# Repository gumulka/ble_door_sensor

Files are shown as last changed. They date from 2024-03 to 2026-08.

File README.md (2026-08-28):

# Bluetooth Window/Door Sensor

A simple project to observe a window or door is open/closed.
It works like most other sensors as well. A magnet has to get attached to the door and
if it comes near the board, it is detected and the state of the window or door is updated.

## How to build

If you are new to Zephyr, read the [Getting Started Guide](https://docs.zephyrproject.org/latest/develop/getting_started/index.html).
Afterwards you can clone and build this project with:

```bash
west init -m https://github.com/gumulka/ble_door_sensor --mr main door_sensor
cd door_sensor
west update
cd ble_door_sensor
```

### Bootloader

The bootloader will load and verify the image that is executed. To make it
easier to upgrade the device, two images are saved on the device and only one is
being executed, while the other is a standby for updating. The bootloader cannot
be upgraded via ble, but the image can be. Therefore making it possible to
upgrade devices in the field.

If you have a unprogrammed device, use this to build and flash the bootloader:

```bash
west build -p -b ble_door_sensor -d build_mcuboot ../bootloader/mcuboot/boot/zephyr/ -- -DCONFIG_BOOT_SIGNATURE_TYPE_ECDSA_P256=y
west flash -d build_mcuboot
```

### Application

The application is different from the bootloader and is what is in need of
updates/upgrades.

```bash
west build -p -b ble_door_sensor app
west flash
```

It is also possible to build the application with debug output for the UART
on the backside of the board.
This is disabled by default as it has a significant influence on battery.

```bash
west build -p -b ble_door_sensor app -- -DEXTRA_CONF_FILE=="debug.conf"
```

### Energy sensor

When I wanted to integrate energy consumption into home assistant without
having to order new hardware, I soldered two resistors to the board and
converted it into an energy monitor.
A 1M Ohm between VCC and AIN0 and 22k Ohm between AIN0 and GND.
This can be configured with:

```bash
west build -p -b ble_door_sensor app -- -DEXTRA_DTC_OVERLAY_FILE=="energy-tracker.dtsi"
```

## Update via BLE

If you have an already running device and just want to upgrade to the latest
firmware.

Either with the nRF Connect App, which can be quite handy, or in the commandline
use these steps:

```bash
sudo mcumgr --conntype ble --connstring ctlr_name=hci0,peer_name='Sensor' image upload build/zephyr/zephyr.signed.bin
sudo mcumgr --conntype ble --connstring ctlr_name=hci0,peer_name='Sensor' image list
```

Use the second hash provided from the second command to alter the following:

```bash
sudo mcumgr --conntype ble --connstring ctlr_name=hci0,peer_name='Sensor' image test "HASH_FROM_OUTPUT"
sudo mcumgr --conntype ble --connstring ctlr_name=hci0,peer_name='Sensor' reset
# wait for the system to restart and if you are sure, that the update was successful then
sudo mcumgr  --conntype ble --connstring ctlr_name=hci0,peer_name='Sensor' image confirm "HASH_FROM_OUTPUT"
```

More information about the general procedure can be found [here](https://docs.zephyrproject.org/latest/samples/subsys/mgmt/mcumgr/smp_svr/README.html)
and [here](https://docs.zephyrproject.org/latest/services/device_mgmt/mcumgr.html)

> [!TIP]
> I have seen a few errors when trying to upload the image and found that it
> works best, if I cancel the upload command after a few seconds and restart it
> a few seconds later, basically splitting the upload into 4-5 chunks instead
> of uploading it as a whole.

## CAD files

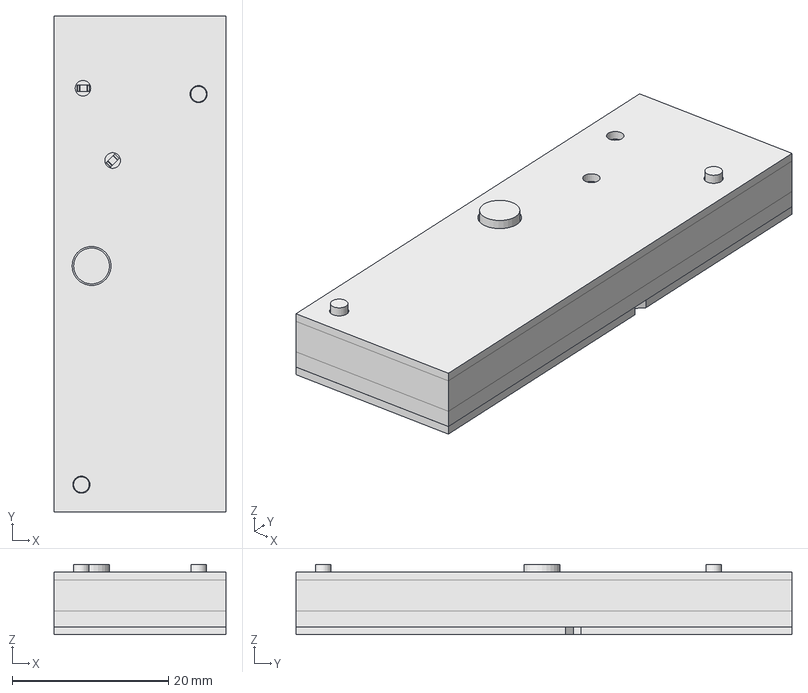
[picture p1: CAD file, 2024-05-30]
Case/Case.FCStd
22.0 x 63.5 x 9.00 mm
Crystal_SMD_3225-4Pin_3.2x2.5mm
C_0402_1005Metric
UQFN-48-1EP_6x6mm_Pitch0.4mm
C_0402_1005Metric002
C_0402_1005Metric004
C_0603_1608Metric
LinkGroup
LinkGroup001
LinkGroup002
L_0603_1608Metric
BatteryHolder_Keystone_3034_1x20mm
R_0402_1005Metric
C_0402_1005Metric006
R_0402_1005Metric002
LED_0603_1608Metric
R_0402_1005Metric004
SHTC1
SHTC002
SHTC003
SHTC004
SHTC005
SHTC006
SHTC007
SHTC008
SHTC009
SHTC010
R_0402_1005Metric006
R_0402_1005Metric008
C_0402_1005Metric008
C_0402_1005Metric010
C_0402_1005Metric012
SOT_23_6
C_0402_1005Metric014
SW_SPST_TL3342
C_0402_1005Metric016
LED_0603_1608Metric002
R_0402_1005Metric010
R_0402_1005Metric012
C_0402_1005Metric018
L_0402_1005Metric
L_0402_1005Metric002
C_0603_1608Metric002
C_0402_1005Metric020
Bottom
Top
Button

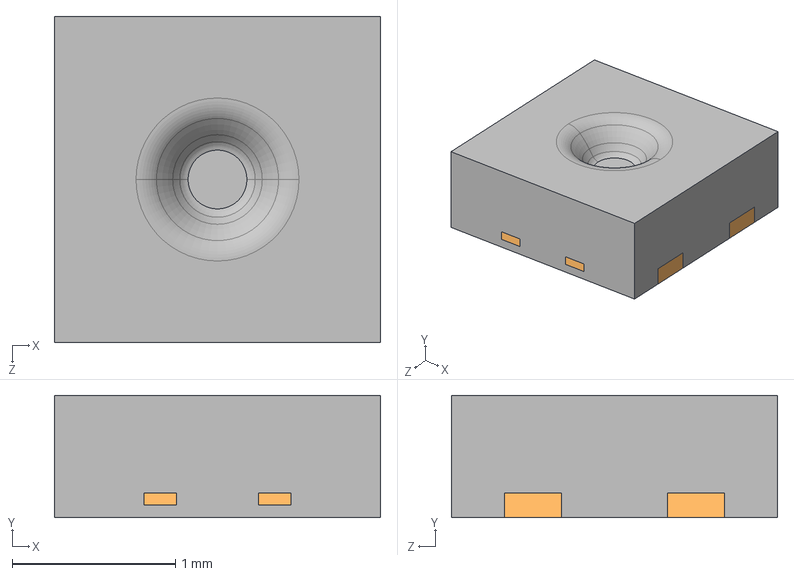
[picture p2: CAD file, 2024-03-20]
kicad/3D-Models/Sensirion-SHTC3.step
2.00 x 0.75 x 2.00 mm

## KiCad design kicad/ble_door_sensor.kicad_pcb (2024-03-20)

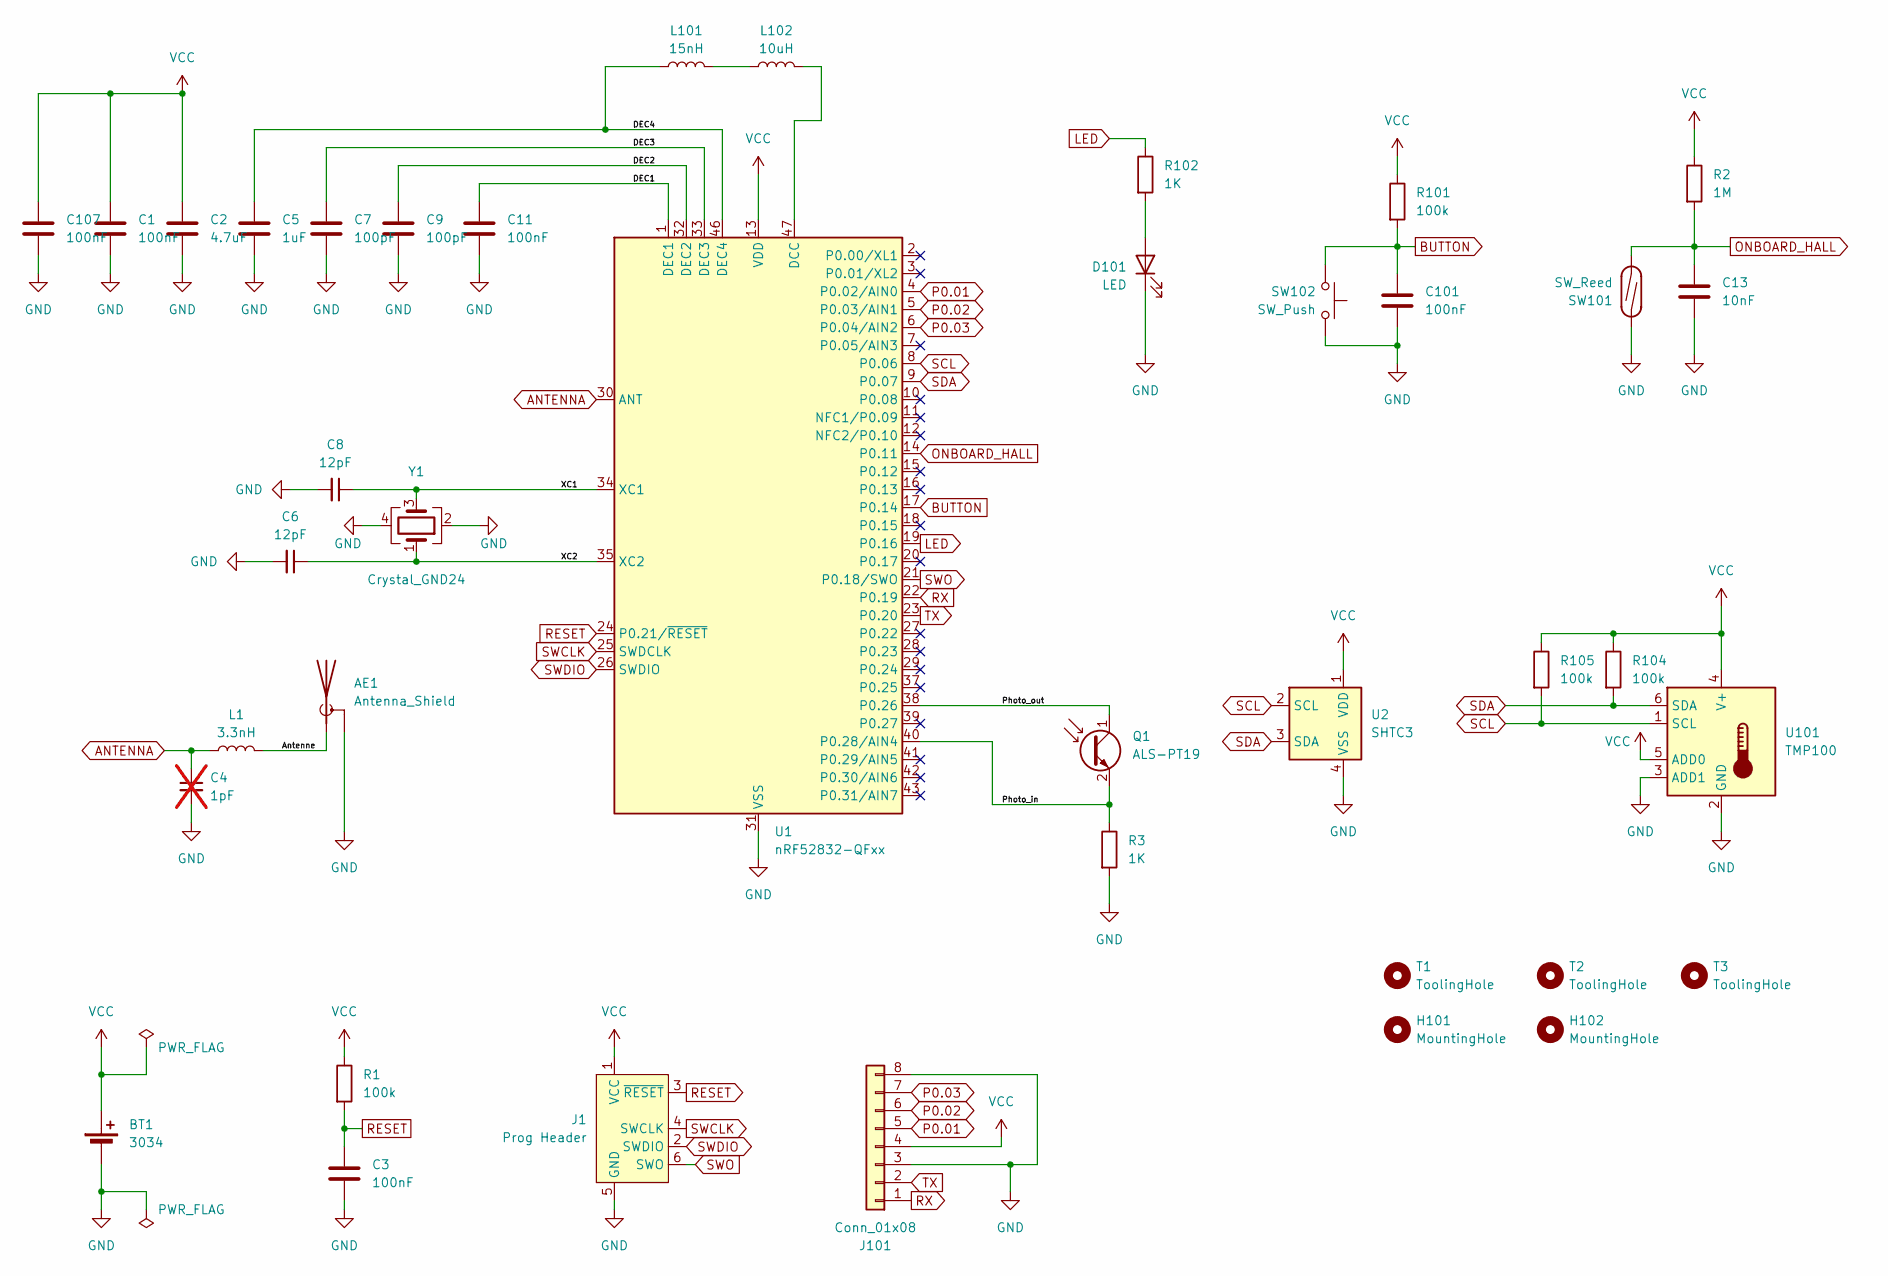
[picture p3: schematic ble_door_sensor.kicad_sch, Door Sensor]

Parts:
AE1: Antenna_Shield; Texas_SWRA117D_2.4GHz_Right
BT1: 3034; BatteryHolder_Keystone_3034_1x20mm; MPN 3034TR; LCSC# C5213768
C1, C3, C11, C101, C107: 100nF; C_0402_1005Metric; MPN 100nF 0402; LCSC# C1525
C2: 4.7uF; C_0603_1608Metric; MPN 4,7uF 0603; LCSC# C19666
C4: 1pF; C_0402_1005Metric; not fitted
C5: 1uF; C_0603_1608Metric; MPN 1uF 0603; LCSC# C15849
C6, C8: 12pF; C_0402_1005Metric; MPN 12pF 0402; LCSC# C1547
C7, C9: 100pF; C_0402_1005Metric; MPN 100pF 0402; LCSC# C1546
C13: 10nF; C_0402_1005Metric; MPN 10nF 0402; LCSC# C15195
D101: LED; LED_0603_1608Metric; MPN KP-1608SGC; LCSC# C72043
H101, H102: MountingHole; MountingHole_2.2mm_M2
J1: Prog Header; Tag-Connect_TC2030-IDC-NL_2x03_P1.27mm_Vertical
J101: Conn_01x08; PinHeader_1x08_P2.54mm_Vertical_SMD_Pin1Left
L1: 3.3nH; L_0402_1005Metric; MPN LQG15HS3N3C02D; LCSC# C14033
L101: 15nH; L_0402_1005Metric; MPN LQW15AN15NH00D; LCSC# C27143
L102: 10uH; L_0603_1608Metric; MPN MLZ1608E100MT; LCSC# C1035
Q1: ALS-PT19; LED_0603_1608Metric; MPN ALS-PT19-315C/L177/TR8; LCSC# C146233
R1, R101, R104, R105: 100k; R_0402_1005Metric; MPN 100K; LCSC# C25741
R2: 1M; R_0402_1005Metric; MPN 1M; LCSC# C26083
R3, R102: 1K; R_0402_1005Metric; MPN 1K; LCSC# C11702
SW101: SW_Reed; reed_contact
SW102: SW_Push; SW_SPST_TL3342; MPN TS-1187A-B-A-B; LCSC# C318884
T1, T2, T3: ToolingHole; JLCPCB_Mounting_hole
U1: nRF52832-QFxx; QFN-48-1EP_6x6mm_P0.4mm_EP4.6x4.6mm; MPN NRF52832-QFAA-R; LCSC# C77540
U2: SHTC3; Sensirion_DFN-4-1EP_2x2mm_P1mm_EP0.7x1.6mm; MPN SHTC3-TR-10KS; LCSC# C2880044
U101: TMP100; SOT-23-6; MPN TMP100NA/3K; LCSC# C31810
Y1: Crystal_GND24; Crystal_SMD_3225-4Pin_3.2x2.5mm; MPN X322532MOB4SI; LCSC# C9009

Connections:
/Antenne: AE1.1 (A), L1.2
/DEC1: C11.1, U1.1 (DEC1)
/DEC2: C9.1, U1.32 (DEC2)
/DEC3: C7.1, U1.33 (DEC3)
/DEC4: C5.1, L101.1, U1.46 (DEC4)
/Photo_in: Q1.2 (E), R3.1, U1.40 (P0.28/AIN4)
/Photo_out: Q1.1 (C), U1.38 (P0.26)
/XC1: C8.1, U1.34 (XC1), Y1.3
/XC2: C6.1, U1.35 (XC2), Y1.1
ANTENNA: C4.1, L1.1, U1.30 (ANT)
BUTTON: C101.1, R101.2, SW102.2, U1.17 (P0.14)
GND: AE1.2 (Shield), BT1.2 (-), C1.2, C2.2, C3.2, C4.2, C5.2, C6.2, C7.2, C8.2, C9.2, C11.2, C13.2, C101.2, C107.2, D101.1 (K), J1.5 (GND), J101.3, J101.8, R3.2, SW101.2, SW102.1, U1.31 (VSS), U1.45 (VSS), U1.49 (VSS), U2.4 (VSS), U101.2 (GND), U101.3 (ADD1), Y1.2, Y1.4
LED: R102.1, U1.19 (P0.16)
unnamed: D101.2 (A), R102.2
unnamed: L101.2, L102.1
unnamed: L102.2, U1.47 (DCC)
ONBOARD_HALL: C13.1, R2.2, SW101.1, U1.14 (P0.11)
P0.01: J101.5, U1.4 (P0.02/AIN0)
P0.02: J101.6, U1.5 (P0.03/AIN1)
P0.03: J101.7, U1.6 (P0.04/AIN2)
RESET: C3.1, J1.3 (~RESET), R1.2, U1.24 (P0.21/~RESET)
RX: J101.1, U1.22 (P0.19)
SCL: R105.2, U1.8 (P0.06), U2.2 (SCL), U101.1 (SCL)
SDA: R104.2, U1.9 (P0.07), U2.3 (SDA), U101.6 (SDA)
SWCLK: J1.4 (SWCLK), U1.25 (SWDCLK)
SWDIO: J1.2 (SWDIO), U1.26 (SWDIO)
SWO: J1.6 (SWO), U1.21 (P0.18/SWO)
TX: J101.2, U1.23 (P0.20)
VCC: BT1.1 (+), C1.1, C2.1, C107.1, J1.1 (VCC), J101.4, R1.1, R2.1, R101.1, R104.1, R105.1, U1.13 (VDD), U1.36 (VDD), U1.48 (VDD), U2.1 (VDD), U101.4 (V+), U101.5 (ADD0)

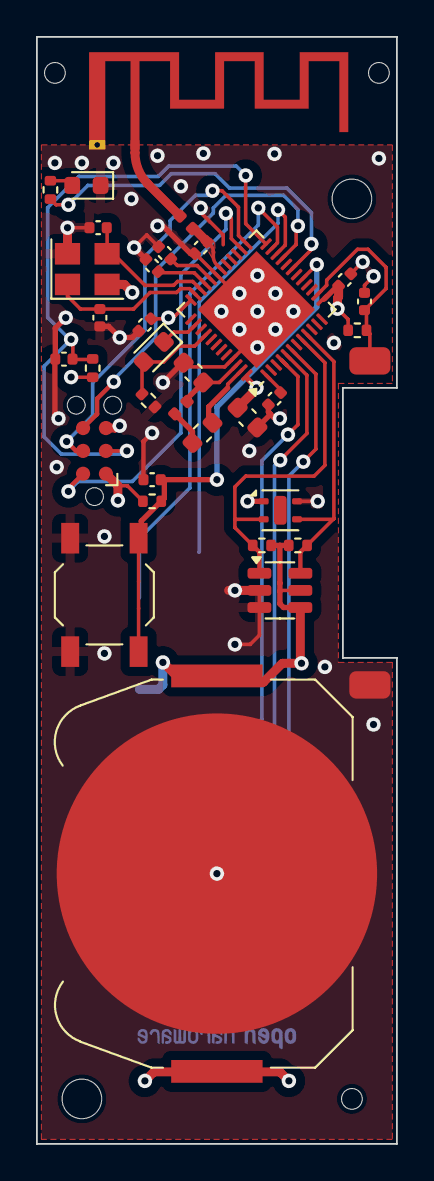
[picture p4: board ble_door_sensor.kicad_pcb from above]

Board: 4 copper layers, 20.0 x 61.5 mm, 40 parts (1 on the bottom side), 29 nets.

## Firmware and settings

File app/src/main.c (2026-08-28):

#include <zephyr/kernel.h>
#include <zephyr/drivers/gpio.h>

#include <zephyr/sys/reboot.h>
#include <zephyr/logging/log_ctrl.h>

#include <zephyr/logging/log.h>
LOG_MODULE_REGISTER(main, CONFIG_APP_LOG_LEVEL);

static const struct gpio_dt_spec led = GPIO_DT_SPEC_GET(DT_ALIAS(led0), gpios);

void k_sys_fatal_error_handler(unsigned int reason, const struct arch_esf *esf)
{
	ARG_UNUSED(esf);

	LOG_PANIC();
	LOG_ERR("Rebooting system");

	sys_reboot(SYS_REBOOT_COLD);

	CODE_UNREACHABLE; /* LCOV_EXCL_LINE */
}

int main(void)
{
	printk("Starting BLE Door Sensor\n");

	// short blink to signal everything is okay
	for(int i = 0; i <3; i++) {
		gpio_pin_set_dt(&led, 1);
		k_msleep(80);
		gpio_pin_set_dt(&led, 0);
		k_msleep(100);
	}

	return 0;
}

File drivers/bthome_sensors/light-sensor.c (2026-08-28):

#include <zephyr/kernel.h>
#include <zephyr/drivers/adc.h>
#include <zephyr/drivers/gpio.h>

#include <lib/bthome.h>

#include <zephyr/logging/log.h>
#define DT_DRV_COMPAT phototransistor_special

LOG_MODULE_REGISTER(phototransistor, CONFIG_BTHOME_SENSORS_LOG_LEVEL);

struct phototransistor_data {
	int8_t illuminance[3];
	bool event;
	struct k_work_delayable work;
	const struct device *dev;
};

struct phototransistor_config {
	const struct adc_dt_spec adc_channel;
	struct gpio_dt_spec enable;
	uint32_t pulldown_ohm;
};

static void light_sensor_update(struct k_work *_work)
{
	struct k_work_delayable *work = k_work_delayable_from_work(_work);
	k_work_reschedule(work, K_SECONDS(CONFIG_BTHOME_LIGHT_SENSOR_UPDATE_INTERVAL));
	struct phototransistor_data *data = CONTAINER_OF(work, struct phototransistor_data, work);
	const struct phototransistor_config *cfg = data->dev->config;

	int32_t raw = 0, val_mv, lux;
	int err;

	struct adc_sequence sequence = {
		.options = NULL,
		.buffer = &raw,
		.buffer_size = sizeof(raw),
		.calibrate = false,
	};

	err = gpio_pin_set_dt(&cfg->enable, 1);
	if (err) {
		LOG_ERR("Could not set enable pin!");
		return;
	}

	err = adc_sequence_init_dt(&cfg->adc_channel, &sequence);
	if (err < 0) {
		LOG_ERR("Could not setup channel err(%d)\n", err);
		return;
	}

	// Wait for output voltage to stabilize
	k_sleep(K_USEC(150));

	err = adc_read_dt(&cfg->adc_channel, &sequence);

	gpio_pin_set_dt(&cfg->enable, 0);

	if (err) {
		LOG_ERR("ADC read error: %d", err);
		return;
	}

	val_mv = raw;
	// If the number is 16 bit signed negative, then there is an error.
	// Especially since we have less then 15 bit resolution.
	if (raw & 0x8000) {
		LOG_ERR("ADC read error, raw value: %d", raw);
		return;
	}
	err = adc_raw_to_millivolts_dt(&cfg->adc_channel, &val_mv);
	if (err) {
		LOG_ERR("ADC conversion error: %d", err);
		return;
	}
	LOG_DBG("Measured: %d -> %d mV", raw, val_mv);

	lux = val_mv;
	lux = 100 * lux * 6666 / cfg->pulldown_ohm;

	LOG_DBG("Light is %d centi lux", lux);
	data->illuminance[0] = lux & 0xFF;
	data->illuminance[1] = (lux >> 8) & 0xFF;
	data->illuminance[2] = (lux >> 16) & 0xFF;

	/* notify bthome, that data has changed */
	bthome_data_changed();
}

static int phototransistor_init(const struct device *dev)
{
	const struct phototransistor_config *cfg = dev->config;
	struct phototransistor_data *data = dev->data;
	int err;

	data->dev = dev;

	if (!gpio_is_ready_dt(&cfg->enable)) {
		LOG_ERR("GPIO port %s is not ready", cfg->enable.port->name);
		return -ENODEV;
	}

	err = gpio_pin_configure_dt(&cfg->enable, GPIO_OUTPUT_INACTIVE);
	if (err < 0) {
		LOG_ERR("Could not configure enable pin!");
		return err;
	}

	if (!adc_is_ready_dt(&cfg->adc_channel)) {
		LOG_ERR("ADC controller device is not ready\n");
		return -ENODEV;
	}

	err = adc_channel_setup_dt(&cfg->adc_channel);
	if (err < 0) {
		LOG_ERR("Could not setup channel err(%d)\n", err);
		return err;
	}

	light_sensor_update(&data->work.work);

	return 0;
}

#define PHOTOTRANSISTOR_DEFINE(inst)                                                               \
	static struct phototransistor_data phototransistor_driver_##inst = {                       \
		.illuminance = {0, 0, 0},                                                          \
		.event = false,                                                                    \
		.work = Z_WORK_DELAYABLE_INITIALIZER(light_sensor_update),                         \
	};                                                                                         \
                                                                                                   \
	BTHOME_DEFINE_SENSOR(phototransistor_##inst, BTHOME_SENSOR_ILLUMINANCE,                    \
			     phototransistor_driver_##inst.illuminance, 3,                         \
			     &phototransistor_driver_##inst.event);                                \
                                                                                                   \
	static const struct phototransistor_config phototransistor_cfg_##inst = {                  \
		.adc_channel = ADC_DT_SPEC_INST_GET(inst),                                         \
		.enable = GPIO_DT_SPEC_INST_GET(inst, enable_gpios),                               \
		.pulldown_ohm = DT_INST_PROP(inst, pulldown_ohm),                                  \
	};                                                                                         \
                                                                                                   \
	DEVICE_DT_INST_DEFINE(inst, phototransistor_init, NULL, &phototransistor_driver_##inst,    \
			      &phototransistor_cfg_##inst, POST_KERNEL,                            \
			      CONFIG_KERNEL_INIT_PRIORITY_DEVICE, NULL);

DT_INST_FOREACH_STATUS_OKAY(PHOTOTRANSISTOR_DEFINE)

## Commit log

2023-12-01 Initial commit send out to production
    [ble_door_sensor.kicad_pcb, ble_door_sensor.kicad_sch]
2024-02-10 Add Zephyr project structure
    Moved hardware files to new subdirectory called kicad.
    [ble_door_sensor.kicad_pcb, ble_door_sensor.kicad_sch]
2024-02-10 First reading out of the hall sensors
    Only printing out a message on change.
2024-02-10 Add BTHome support
    Transmitting the sensor values via BTHome advertisement data
2024-02-10 Add battery voltage to measurement data
    measure the SOC voltage and calculate a battery percentage from it
    Not good, but better then nothing
2024-02-10 Optimizing power consmption
    reducing BLE adv schedule to only once per 10 seconds
    Disabling UART by default.
2024-02-14 Add footprint for reed sensor
2024-02-14 Updated schematic
    [ble_door_sensor.kicad_sch]
2024-02-14 First rough placement
    Updated some footprints in the process to better fit my needs
    Holes are in 5mm grid to each other 15mm in x and 45 mm in y apart
    Board outline is 20x80mm
    [ble_door_sensor.kicad_pcb, ble_door_sensor.kicad_sch]
2024-02-14 First routing
    Replaced Testpoints with SMD pinheader
    Added more Testpoints
    Reduced board outline to 20x70mm
    Mounting holes are now 15x35mm apart
    [ble_door_sensor.kicad_pcb, ble_door_sensor.kicad_sch]
2024-02-14 Put the reed contact on the top side
    I want to glue the PCB to some surfaces and having something on the
    bottom side is very contraproductive.
    [ble_door_sensor.kicad_pcb, ble_door_sensor.kicad_sch]
2024-02-16 Add Temperature sensor instead of external reed
    Remove the contacts fro external reed contacts
    Add temperature sensor
    Reduce the size of the PCB
    Add additional mounting hole
    [ble_door_sensor.kicad_pcb, ble_door_sensor.kicad_sch]
2024-02-23 Add tmp100 sensor for temperature
    also added mounting holes for assembly machines
    [ble_door_sensor.kicad_pcb, ble_door_sensor.kicad_sch]
2024-02-26 Add ambient light and humidity sensor
    [ble_door_sensor.kicad_pcb, ble_door_sensor.kicad_sch]
2024-02-29 Add MPN and Manufacturer for most parts
    To be able to order from different houses
    [ble_door_sensor.kicad_pcb, ble_door_sensor.kicad_sch]
2024-03-19 Update to Kicad 8
    [ble_door_sensor.kicad_pcb, ble_door_sensor.kicad_sch]
2024-03-20 Add 3D-Model of humidity sensor
    [Sensirion-SHTC3.step, ble_door_sensor.kicad_pcb]
2024-03-20 Move footprints to new library
    [ble_door_sensor.kicad_pcb, ble_door_sensor.kicad_sch]
2024-05-04 Update zephyr devicetree to new revision
    I don't plan on using the first revision ever again, therefor there is
    no need to preserve the devicetree for the old revision.
2024-05-04 Add support Temperature/Humidity sensor
    First support for reading out values from the dual sensor.
2024-05-07 Add support for update over the air
    Using MCUBOOT as a bootloader and partition the device into A/B
    schema to have a somewhat save update.
    During updateting, the device often did halt, so instead of halting the
    system I overwrote the error handler to reboot instead, making it
    possible to restart the update without having to manually restarting
    the device.
    Update is currently mostly just copied from SMP_SVR and needs some
    finetuning.
    [main.c]
2024-05-11 Fix high current consumption
    There is a hardware bug on the SOC that I'm using, which has to have
    a workaround when using i2c and gpiote at the same time, which i do.
2024-05-11 Move environment sensor measurements out of main
    to have a better overview of the sensors and where the data gets
    collected, I started to separate the main file into multiple.
2024-05-11 Move interrupt sensors into its own file
    Interrupts may be able to reschedule the reading of sensors and
    trigger with it a reading of themself.
2024-05-11 Differentiate between short and long button press
2024-05-11 Move battery measurement scale
    Old was from 2.5 to 3.3V
    New is 2.0 to 3.0, which is much more realistic for 2032 batteries
2024-05-11 Remove power management from light sensor
2024-05-30 Added hints about i2c addresses
    [ble_door_sensor.kicad_sch]
2024-05-30 Add datasheet for humidity sensor
2024-05-30 Ad case for device.
    Case designed in FreeCAD and needs some more love, but good enough
    for a first draft.
    [Case.FCStd]
2026-08-28 Add bthome library for sensor collection
    The library collects data from sensors, which can be dynamically
    generated and added to the pool of available sensors.
    This way the implementation of sending out data is not so hard
    interwoven with the available sensors.
2026-08-28 drivers: light-sensor: use bthome api
    Convert the light sensor to use the bthome api to update its data.
2026-08-28 board: allow flashing with more programmers
    Makes it also a bit faster.
2026-08-28 drivers/bthome: add energy tracker
    A tracker to check if an LED is blinking with the Phototransistor
    connected to a ADC, which gets compared to a resistor bridge.
    If the LED goes off, 1Wh has been consumed.
    This allows to track it.
2026-08-28 drivers/bthome: add sensor for battery percent
    The calculation is not really sophisticated, but it works as an
    approximation to add the battery voltage to BT advertisement data.
2026-08-28 drivers/bthome: add temperature and humidity
    Combined sensor, which can selectively only expose one of its values.
2026-08-28 drivers/bthome: add binary gpio sensor
    Use a gpio to toggle a binary sensor.
2026-08-28 drivers/bthome: add butten sensor
    It is able to detect all kinds of press events and propate them. New
    events overwrite old ones and there is a short debouncer integrated.
    [button.c]
2026-08-28 app: use new bthome drivers
    Configure all drvers in the devicetree and keep the main function
    (mostly) empty. There is only a hello message and LED blinking to
    indicate, that the device has bootet.
2026-08-28 add overlay for energy tracker functionality
    The energy tracker uses the light sensor to track if my energy meter's
    led is blinking to track energy usage. There might be some missing
    blinks, but it is good enough.
